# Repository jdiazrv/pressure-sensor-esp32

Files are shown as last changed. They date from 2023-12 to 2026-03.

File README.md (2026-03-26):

# ESP32 Pressure Sensor for MAB WaterMaker

ESP32-based dual pressure monitor for a MAB WaterMaker system.
It reads two 0.5-4.5 V pressure transducers through an ADS1115, shows the values on a local dashboard and OLED, and publishes the data to SignalK over UDP.

This project is the ESP32 evolution of the original `8266-pressure-sensor`, adapted for the same hardware concept and marine workflow with a more complete web UI, better diagnostics, demo modes, OTA updates, and more robust SignalK discovery.

## Release Notes

### v1.5

- LED state machine consolidated and aligned with connectivity/error priorities
- Fast dual-LED blink alarm when ADS1115 is missing in real mode
- ADS1115 startup detection across addresses `0x48-0x4B` with I2C diagnostics on failure
- Dashboard now includes sensor voltages on both pressure cards
- Manual SignalK target now accepts `ip:port` in UI
- Dashboard `Last reading` update made robust
- Min/max range markers consolidated into periodic one-minute updates
- Removed duplicated card status text while preserving color status chip (`Warning/Normal/Alarm`)

## Features

- Dual pressure acquisition with ADS1115
- OLED local display
- Responsive dashboard served from LittleFS
- SignalK UDP output with automatic discovery
- Manual SignalK IP override from the UI
- Configurable and persistent UDP port
- Real, Demo, and Demo + UDP modes
- Device diagnostics page
- SignalK monitor page with live scrolling log
- Firmware OTA update from the browser
- Filesystem OTA update from the browser
- AP mode or client mode with WiFiManager fallback
- Detection of:
  - ADS1115 missing
  - no signal from sensor
  - disconnected sensor
  - stale sensor data

## Hardware

- ESP32 dev board
- ADS1115 ADC
- 2 pressure sensors with 0.5-4.5 V output
- Small I2C OLED
- 5 V regulated supply

The original hardware concept and documentation come from the earlier 8266 project and are still relevant here.

## Pressure Channels

- Sensor 1: low pressure / inlet pressure
- Sensor 2: high pressure / main pressure

Default calibration:

- Sensor 1: `0.5-4.5 V` => `0-15 bar`
- Sensor 2: `0.5-4.5 V` => `0-80 bar`

Dashboard visual ranges:

- Low pressure gauge: `0-4 bar`
- High pressure gauge: `0-70 bar`

## WiFi Modes

`Client`

- Connects to an existing WiFi network
- Tries to discover a SignalK server with mDNS
- Publishes UDP to the configured or discovered target

`AP only`

- Creates a local access point for direct access
- Useful for standalone setup and service work

## Sensor Source Modes

`Real`

- Reads ADS1115 hardware
- Sends UDP only when ADS1115 is detected

`Demo`

- Generates realistic simulated pressures
- Does not send UDP

`Demo + UDP`

- Generates simulated pressures
- Sends them through the same UDP pipeline for testing

## Web Interface

Main dashboard:

- Large low and high pressure cards
- RSSI indicator
- SignalK status pill
- Clickable status details with firmware/UI version and current error

Settings:

- Calibration for both sensors
- WiFi mode
- sensor source mode
- AP password
- SignalK retry count
- SignalK IP
- UDP port

Maintenance:

- firmware update
- filesystem update
- tools
- factory reset

Tools:

- device diagnostics
- SignalK monitor

## OTA Updates

The device supports browser-based OTA:

- `/update` for firmware
- `/updatefs` for LittleFS filesystem image

It also exposes ArduinoOTA for LAN updates.

## SignalK Output

The device publishes:

- `environment.watermaker.pressure.low`
- `environment.watermaker.pressure.high`

Current mapping:

- low pressure comes from Sensor 1
- high pressure comes from Sensor 2

## Filesystem Content

The web UI is stored in `data/` and uploaded to LittleFS.

Important files:

- `data/index.html`
- `data/gauge.min.js`
- `data/manifest.webmanifest`
- `data/icon.svg`

## Build And Upload

This project uses PlatformIO.

### Build

```bash
platformio run -e esp32dev
```

### Upload Firmware

```bash
platformio run -e esp32dev -t upload
```

### Upload Filesystem

```bash
platformio run -e esp32dev -t uploadfs
```

### Serial Monitor

```bash
platformio device monitor -b 115200
```

## Project Structure

- [`src/main.cpp`](src/main.cpp): firmware logic
- [`src/config_html.h`](src/config_html.h): settings page HTML
- [`data/index.html`](data/index.html): dashboard UI
- [`platformio.ini`](platformio.ini): PlatformIO environment
- [`res/gauges.jpeg`](res/gauges.jpeg): legacy gauge reference
- [`res/Schematics.png`](res/Schematics.png): hardware reference
- [`res/pressure_pcb.png`](res/pressure_pcb.png): PCB reference
- [`res/pressure_bom.html`](res/pressure_bom.html): BOM reference

## Legacy Reference

This repository derives from the original 8266 project:

- https://github.com/jdiazrv/8266-pressure-sensor

Relevant hardware concepts, gauge ranges, PCB references, and documentation were carried forward and adapted for the ESP32 implementation.

## License

See [LICENSE.md](LICENSE.md).

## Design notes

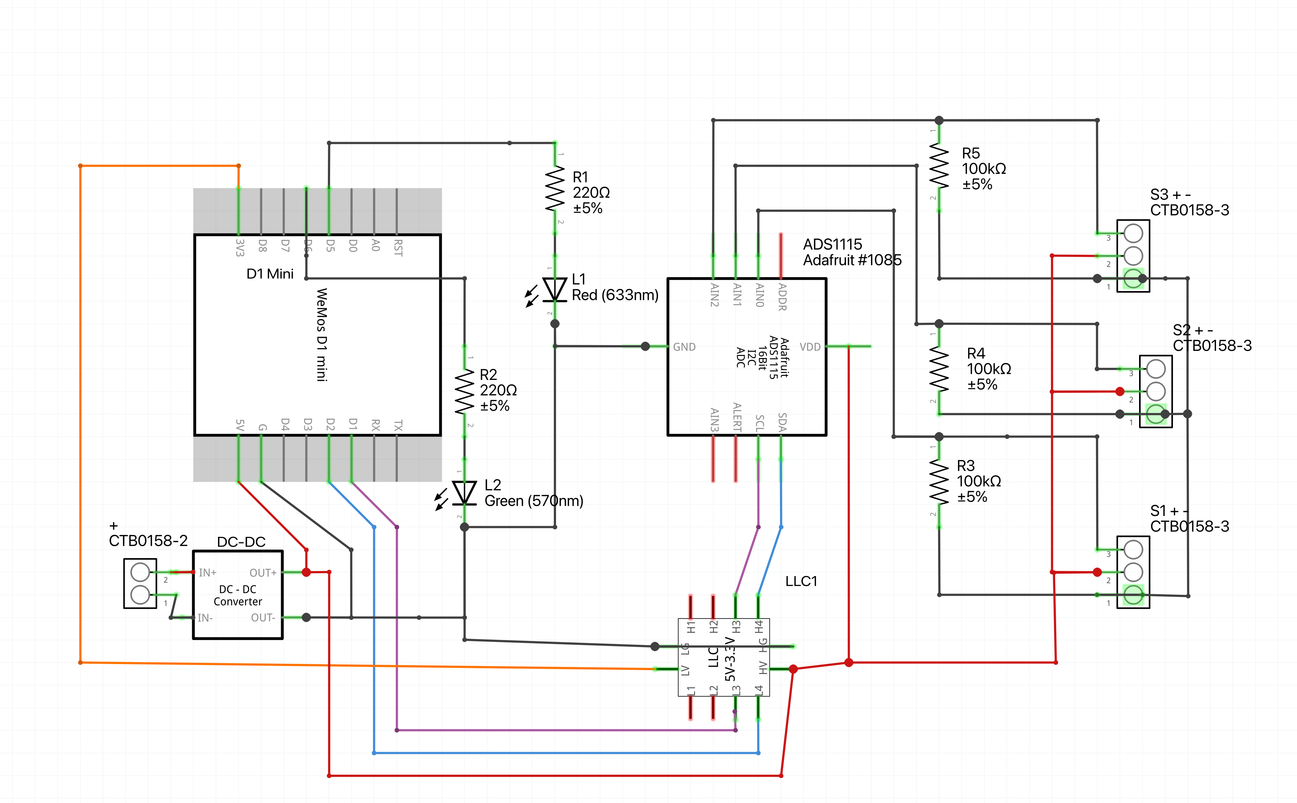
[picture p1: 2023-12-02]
res/Schematics.png

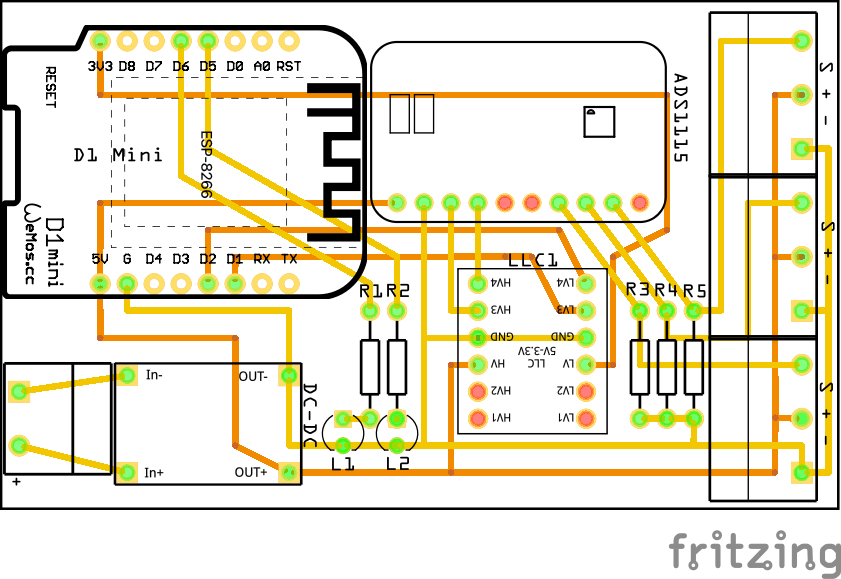
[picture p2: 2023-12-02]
res/pressure_pcb.png

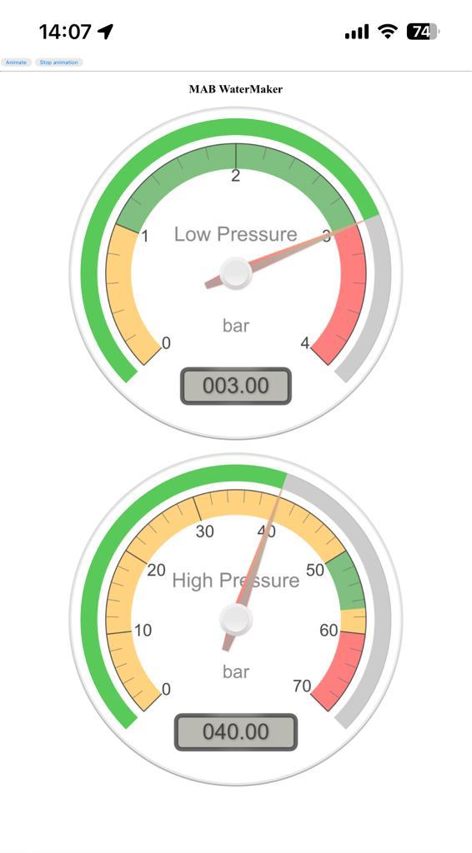
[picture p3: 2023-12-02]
res/gauges.jpeg

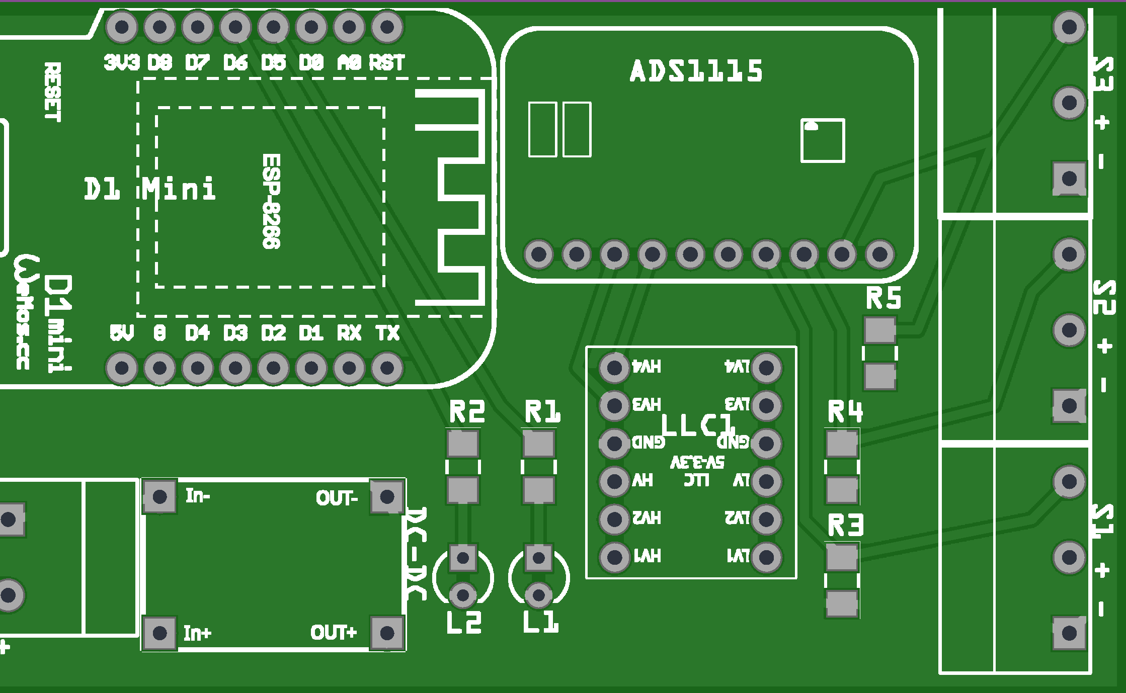
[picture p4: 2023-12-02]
res/PCB.png

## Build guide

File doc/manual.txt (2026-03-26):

MAB WaterMaker - Pressure Sensor ESP32
Manual operativo (v1.5)

1) Resumen
- El equipo mide dos presiones con ADS1115.
- Publica datos por web local y por UDP para SignalK.
- Permite modo real, demo y demo+UDP.

2) Entradas y canales
- Sensor 1: presion baja (feed/inlet).
- Sensor 2: presion alta (main).
- Rango por defecto de sensores: 0.5-4.5 V.

3) Red y acceso
- En modo cliente (STA), intenta conectarse al WiFi configurado.
- Si no hay credenciales, levanta portal de configuracion con WiFiManager.
- Dashboard principal: / (raiz del dispositivo).
- Ajustes: /config.

4) SignalK
- Descubrimiento automatico por mDNS.
- Configuracion manual de IP desde dashboard.
- Se acepta formato ip o ip:puerto (ejemplo: 192.168.1.10:3000).
- Puerto de servicio SignalK por defecto: 3000.
- Puerto UDP configurable (por defecto 4210).

5) Indicacion por LEDs (v1.5)
- Error ADS1115 en modo real: parpadeo rapido en los dos LEDs.
- AP only: LED1 doble pulso, LED2 apagado.
- WiFi desconectado/conectando: LED1 parpadeo medio (o triple pulso en ventana portal), LED2 apagado.
- WiFi conectado:
	- SignalK buscando: LED2 doble pulso.
	- SignalK OK: LED2 fijo (si no hay timeout de datos).
	- SignalK sin respuesta: LED2 parpadeo medio.

6) Dashboard (v1.5)
- Muestra presion baja/alta y voltaje de cada canal.
- Chip de estado por color: Warning / Normal / Alarm.
- "Last reading" actualizado de forma robusta.
- Marcadores min/max de barra actualizados periodicamente en bloques de 1 minuto.

7) Deteccion ADS1115
- Escaneo de direcciones validas: 0x48, 0x49, 0x4A, 0x4B.
- Si no lo detecta, registra diagnostico I2C por serie.

8) OTA
- Firmware: /update.
- Filesystem: /updatefs.

9) Build y carga (PlatformIO)
- Compilar firmware: platformio run -e esp32dev
- Subir firmware: platformio run -e esp32dev -t upload
- Subir filesystem: platformio run -e esp32dev -t uploadfs

10) Notas de diagnostico
- Si no hay lecturas en modo real: verificar alimentacion, GND comun, cableado ADS1115, y direccion ADDR.
- Si hay dashboard pero no SignalK: revisar IP/puerto, mDNS y firewall de la red.

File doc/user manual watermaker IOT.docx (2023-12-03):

# WaterMaker IoT Pressure Monitor: User Guide

## Welcome

Welcome to the WaterMaker IoT Pressure Monitor, an innovative device designed for the MAB WaterMaker system (http://watermaker.se). While the MAB WaterMaker system is fully functional with its incorporated analog devices, this device adds an extra layer of monitoring and convenience, allowing you to monitor and receive alerts even when away from the watermaker's control panel, like in the cockpit of the vessel. This user guide will provide you with detailed information about the setup, use, and how to integrate this device into your monitoring system.

## Device Functionality

The MAB WaterMaker is equipped with all indicators for its operation in a safe manner. However, it is convenient to regularly monitor the pressures while it works to ensure proper functioning. This can be done by looking at the watermaker control panel or remotely with this device.

The device is equipped with two high-precision pressure sensors. These sensors are responsible for measuring and recording the pressure in your water purification system. The sensors operate in different pressure ranges:

- The first sensor monitors low-pressure circuits and can measure values in the range of 0 to 4 bar.
- The second sensor takes care of high-pressure circuits and can record values in the range of 0 to 70 bar.

## Operating Modes

The device can operate in two main modes: Station and AP (Access Point).

1. Station Mode: In this mode, the device connects to an existing WiFi network. You can configure the device to connect to your home WiFi network or to a specific network on your vessel. If for some reason it cannot connect to the preconfigured network (for example, if the network is not available or incorrect credentials were entered), the device will initiate and temporarily create a WiFi network called 'watermaker_config'. This will allow you to select or reconfigure the WiFi network directly from the device. Also, in this mode, the software will automatically search for the SignalK server, simplifying integration with boat instrumentation systems.
2. AP (Access Point) Mode: In this mode, the WaterMaker IoT Pressure Monitor creates its own WiFi network called 'watermaker'. This mode is useful when you do not have access to an existing WiFi network. You can configure a password for this WiFi network to ensure secure access. You can access the device in this mode through the hostname 'watermaker.local' or via the default IP address '192.168.4.1'.

## Remote Monitoring

A standout feature of this device is its ability to allow remote monitoring of your WaterMaker system. This means you can check the status of your system in real time from any location. Whether you are inside your vessel or on land (if you have configured the router for remote access), you can access the pressure data and ensure that your system is functioning correctly.

## Web Interface for Pressure Monitoring


Once you access watermaker.local through your web browser, the interface will show two radial gauges, each displaying a different aspect of the watermaker's operation:

### Low Pressure Gauge

- Range: 0 to 4 bar
- Color-Coded Highlights:
  - Orange Zone (0-1 bar): Low-pressure warning.
  - Green Zone (1-3 bar): Normal operating pressure range.
  - Red Zone (3-4 bar): High-pressure warning.

### High Pressure Gauge

- Range: 0 to 70 bar
- Color-Coded Highlights:
  - Orange Zone (0-50 bar): Preparatory pressure range.
  - Green Zone (50-57 bar): Normal operating pressure range.
  - Orange Zone (57-60 bar): Transition or caution area.
  - Red Zone (60-70 bar): High-pressure warning.

These gauges are designed to provide clear and intuitive feedback on the system's status, with green zones specifically marking the ideal operating pressures. Users can conveniently monitor the watermaker's performance and ensure it operates within safe and efficient pressure ranges. Data is received in the SignalK Server, consequently it can be displayed with KIP or with third-party apps such as WillHelm SK.

## Sensor configuration

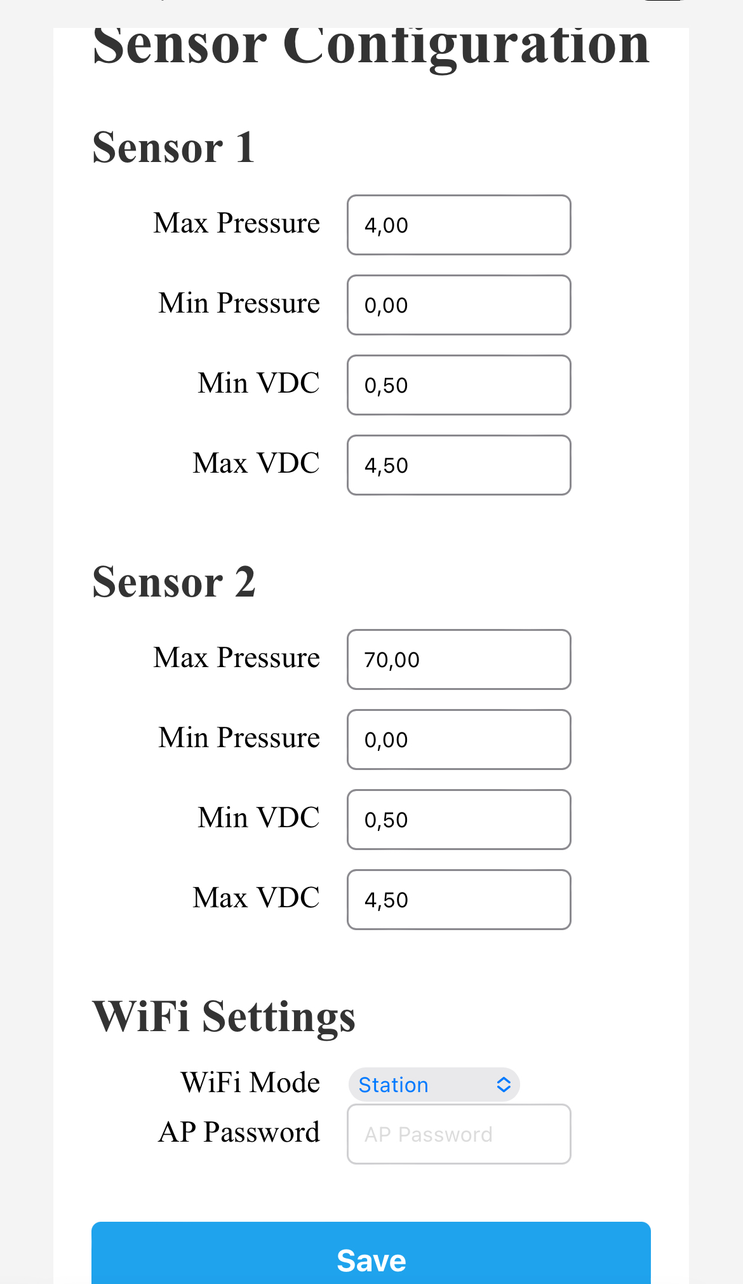
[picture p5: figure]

The sensors used in the WaterMaker IoT Pressure Monitor must meet certain specifications to function properly with the device. Here are the key specifications they should adhere to:

1. Power Supply: The sensors should be capable of operating with a 5VDC power source. This means they should be able to function with a voltage of 5 volts of direct current.
2. Maximum Signal Voltage: The sensor should be able to provide a voltage signal within the range of 0 to 4.5 volts, depending on the maximum pressure expected to be measured. This ensures that the sensor can effectively transmit pressure information to the WaterMaker IoT Pressure Monitor.
3. Threaded Connection: For sensor installation, a high-pressure "T" with a male G1/4 thread, a female G1/4 thread, and a female thread that matches the sensor's thread should be used. This ensures a proper and sealed connection for accurate pressure measurement.

As for sensor configuration, it is done on the configuration page, which can be accessed in two ways:

- From the wheel icon in the upper-right corner of the "gauges" screen in the web interface of the WaterMaker IoT Pressure Monitor.
- Directly by entering the web address "watermaker.local/config" in a web browser.

On this configuration page, users can adjust sensor parameters such as pressure ranges to match the specific characteristics of the sensor they are using. This ensures that the sensors are correctly configured to provide accurate measurements and adapt to the expected operating conditions.

## Indicator Lights

Red LED (Status Indicator)

- Solid On: The red LED remains solidly lit when the device is powered. This indicates that the device is receiving power and is operational.
- LED Off: The red LED turns off when the device successfully establishes a connection to the network. This signifies that the device is connected to a network, either through Station Mode (connecting to an existing WiFi network) or Access Point (AP) Mode (creating its own WiFi network).
- Blinking (Flashing): The red LED blinks or flashes each time data is transmitted to the SignalK server. This serves as a visual confirmation that the device is actively sending pressure data to the SignalK server, indicating its functionality and data communication activity.

## Integration with SignalK

The device is designed to automatically connect to the SignalK server when in Station mode. SignalK is an open-source standard for boat navigation that allows the integration of data from different systems and sensors. The WaterMaker IoT Pressure Monitor sends pressure data to the SignalK server via port 4210. This allows you to use SignalK-compatible monitoring applications to visualize and analyze the pressure data.

## SignalK Configuration

The WaterMaker IoT Pressure Monitor is designed to automatically connect to the SignalK server when in Station mode. The device will send data through port 4210 of the SignalK server. To configure the SignalK server and receive data from the device, follow these steps:

- Access the SignalK Web Interface: Open the SignalK web interface from your web browser and make sure you are logged into your SignalK account if necessary.
- Navigate to Connection Configuration: In the SignalK web interface, look for the connection configuration section or data sources. This is usually found in server settings or a similar configuration menu.
- Add a New UDP Connection: Within the connection configuration section, look for the option to add a new UDP connection. It may have a name like "Add Connection" or similar.
- Configure the UDP Connection:
  - Data Type: Specify "SignalK" as the expected data type.
  - UDP Port: Enter "4210" as the UDP port number to which the WaterMaker IoT Pressure Monitor will send data.
- Save the Configuration: Once you have specified the data type as "SignalK" and configured the UDP port as "4210", make sure to save the settings. You will usually find a button or an option to save changes.
- Verify the Configuration: After saving the settings, verify that the UDP connection is active and working correctly. You can check the SignalK web interface to confirm that the data is being received and processed according to the SignalK standard.

By following these steps, you will have correctly set up a UDP connection in SignalK to receive data from the WaterMaker IoT Pressure Monitor on port 4210. This will allow SignalK to interpret and process the pressure data according to the SignalK standard, facilitating its visualization and analysis in SignalK-compatible applications or on the SignalK web interface.

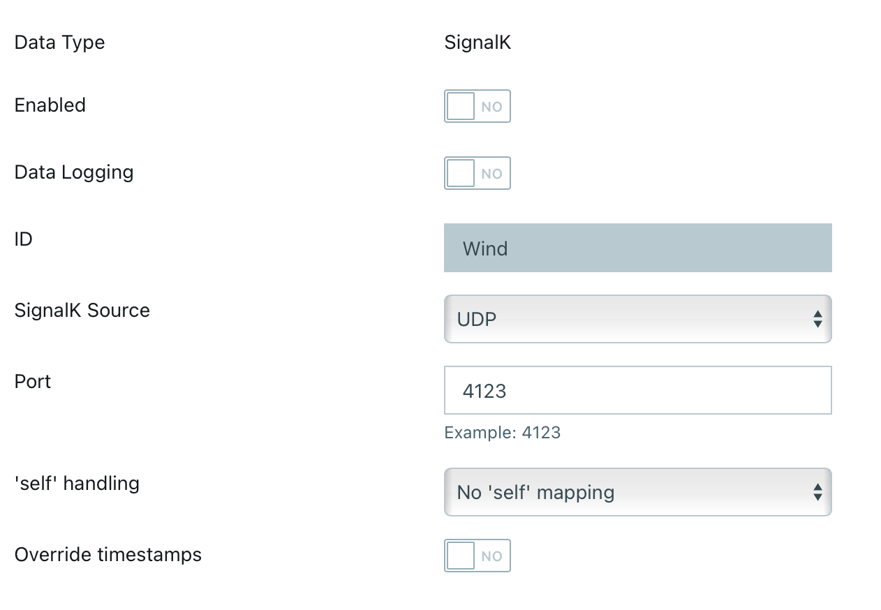
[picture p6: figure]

## Custom Alerts

In addition to real-time monitoring, the WaterMaker IoT Pressure Monitor allows you to set up custom alerts. You can set specific pressure thresholds and receive instant notifications in case abnormal pressure conditions are detected. These alerts provide an additional layer of safety and allow you to take immediate action in case of issues with your WaterMaker system. The configuration of the alerts is done on the SignalK server with the necessary plugins or for advanced users with Node-red.

## Access Point (AP) Password Reset

If you forget the configured password for the AP (Access Point) mode on the WaterMaker IoT Pressure Monitor, you can reset it to the default factory password, which is "12345678". Follow these steps to do so:

1. Locate the physical reset button on the WaterMaker IoT Pressure Monitor device.
2. Briefly press the reset button once. It is not necessary to hold it pressed for a long time.
3. After pressing the reset button, the AP password will automatically reset to the default password "12345678".
4. You can now connect to the AP mode using the default password "12345678".

Remember that, after resetting the AP password, it is advisable to set a new secure password to ensure the security of your network. You can do this through the device's web configuration interface.

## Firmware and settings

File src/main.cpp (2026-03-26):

// Pressure Sensor ESP32 - SignalK Watermaker
// Based on Chain Counter ESP32 mejorado v3.7
// Dual pressure sensor with SignalK integration
// Changelog:
//   v1.6
//     Change: UDP send interval reduced from 2s to 1s for faster APK updates
//     Add: voltage1 and voltage2 included in UDP payload for APK display
//   v1.5
//     Add: LED state-machine patterns aligned with project status priorities
//     Add: both LEDs blink fast when ADS1115 is missing in real mode
//     Fix: ADS1115 detection scans all valid addresses (0x48-0x4B) with I2C diagnostics
//     Fix: dashboard renders live bars when readings are available even with device warnings
//     Add: voltage values in /pressure JSON and on both dashboard cards
//     Fix: SignalK manual target accepts ip:port format from UI
//     Fix: Last reading timestamp updates reliably in dashboard polling loop
//     Change: min/max range markers now update with periodic one-minute buckets
//     Change: removed duplicated card status text while keeping color label chip
//   v1.4
//     Add: I2C mutex for bus serialization (ADS1115 + OLED)
//     Add: OtaState struct for coherent OTA state management
//     Add: RuntimeState struct for sensor/runtime data encapsulation
//     Add: UDP resync helpers (invalidateUdpLastSent, resetUdpPressureHistory)
//     Add: Display refresh separated from page switching (1s vs 5s)
//     Add: Sensor reading refactored into cohesive helpers
//     Fix: OLED access removed from taskNetwork (no cross-core I2C race)
//     Fix: All I2C operations protected with lockI2C()
//     Fix: OTA handlers use otaState.error as single source of truth
//     Fix: WiFi reconnection uses WiFi.begin() without cached credentials
//     Fix: Event_Submit preserves existing values when fields missing
//     Fix: Event_MonitorData minimizes lock time (snapshot pattern)
//     Fix: SignalK IP handler reads servicePort under lock
//     Fix: OLED startup screen wrapped with i2cMutex
//     Fix: showNetworkPage passed as parameter (no global state)
//     Fix: signalkCtx initialization under lockState in readPreferences()
//     Fix: ConfigSnapshot separated from runtime state
//     Change: updatePressureReadings split into focused helpers
//     Change: writePreferences split into config/signalK/runtime domains
//     Change: applySettingsPayload uses unified SignalK source-of-truth
//     Remove: dead globals (pressure1/2, voltage1/2, previousMillis, intervalForAP, isFirstBoot)
//   v1.3
//     Add: dedicated mutex for monitor ring buffer reads/writes
//     Fix: preserve discovered SignalK service port when saving settings
//     Fix: monitor API now reads buffered lines under monitor lock
//     Fix: sensor/error debug logging now snapshots shared values before logging
//     Fix: pressure/meta/state JSON now use consistent escaping for error text
//     Change: settings JSON parsing now applies overrides on top of the current payload state
//     Change: submit/settings handlers now use runtime snapshots instead of raw shared reads
//   v1.2
//     Add: password-only auth on config, OTA and factory reset routes
//     Add: dedicated admin credentials separated from AP password
//     Add: lightweight admin session cookie for protected routes
//     Add: shared-state mutex for sensor/network/runtime snapshots
//     Add: I2C bus hardening with 100 kHz clock and timeout
//     Add: password confirmation and reveal toggles on device settings
//     Change: /config now opens a public settings menu and /device-settings stays protected
//     Change: device settings page focuses on settings only, without maintenance shortcuts
//     Change: dashboard and admin UI text unified in English
//     Change: runtime NVS checkpoint relaxed to 15 min to reduce flash wear
//   v1.1
//     Fix: Sensor 2 factory max pressure corrected to 80 bar
//     Fix: SignalK UDP mapping corrected to low/high semantic paths
//     Add: SignalK HTTP health probe via /signalk every 15 s
//     Add: automatic rediscovery when a previously reachable SignalK server disappears
//     Fix: dashboard SignalK pill now reflects real server availability
//     Fix: dashboard uses backend data validity instead of guessing from pressure values
//     Fix: UDP monitor distinguishes local send success from local send failure
//   v1.0
//     Add: SignalK discovery with robust .local hostname resolution
//     Fix: do not overwrite configured UDP port with SignalK websocket service port
//     Add: persistent SignalK IP and UDP port configuration in NVS
//     Add: sensor source modes Real / Demo / Demo + UDP
//     Add: HTTP OTA for firmware and filesystem update
//     Add: UI status details with FW/UI version and device error reporting
//     Add: ADS1115 missing, no-signal, and disconnected sensor detection
//     Add: SignalK IP edit from UI and LittleFS-served dashboard updates

#include <Arduino.h>
#include <WiFi.h>
#include <WebServer.h>
#include <Preferences.h>
#include <WiFiUdp.h>
#include <ESPmDNS.h>
#include <WiFiManager.h>
#include <Update.h>
#include <Wire.h>
#include <Adafruit_ADS1X15.h>
#include <Adafruit_GFX.h>
#include <Adafruit_SSD1306.h>
#include <ArduinoJson.h>
#include <LittleFS.h>
#include "config_html.h"

// ── Versión del software ───────────────────────────────────────────────────────
#define SW_VERSION "v1.6"

// ── Nivel de debug ──────────────────────────────────────────────────────────────
// 0 = sin logs
// 1 = errores
// 2 = info
// 3 = verbose
#define DEBUG_LEVEL_ERROR 1
#define DEBUG_LEVEL_INFO 2
#define DEBUG_LEVEL_VERBOSE 3
#define DEBUG 0

// Macros de logging
#define LOG_ERR(msg)                      \
    do                                    \
    {                                     \
        if (DEBUG >= DEBUG_LEVEL_ERROR)   \
            Serial.println("[ERR] " msg); \
    } while (0)
#define LOG_ERRF(fmt, ...)                                   \
    do                                                       \
    {                                                        \
        if (DEBUG >= DEBUG_LEVEL_ERROR)                      \
            Serial.printf("[ERR] " fmt "\n", ##__VA_ARGS__); \
    } while (0)
#define LOG_INF(msg)                      \
    do                                    \
    {                                     \
        if (DEBUG >= DEBUG_LEVEL_INFO)    \
            Serial.println("[INF] " msg); \
    } while (0)
#define LOG_INFF(fmt, ...)                                   \
    do                                                       \
    {                                                        \
        if (DEBUG >= DEBUG_LEVEL_INFO)                       \
            Serial.printf("[INF] " fmt "\n", ##__VA_ARGS__); \
    } while (0)
#define LOG_VRB(msg)                      \
    do                                    \
    {                                     \
        if (DEBUG >= DEBUG_LEVEL_VERBOSE) \
            Serial.println("[VRB] " msg); \
    } while (0)
#define LOG_VRBF(fmt, ...)                                   \
    do                                                       \
    {                                                        \
        if (DEBUG >= DEBUG_LEVEL_VERBOSE)                    \
            Serial.printf("[VRB] " fmt "\n", ##__VA_ARGS__); \
    } while (0)

// ── Valores por defecto / fábrica ───────────────────────────────────────────────
#define MIN_VOLTAGE1 0.5
#define MAX_VOLTAGE1 4.5
#define MIN_PRESSURE1 0
#define MAX_PRESSURE1 15
#define MIN_VOLTAGE2 0.5
#define MAX_VOLTAGE2 4.5
#define MIN_PRESSURE2 0
#define MAX_PRESSURE2 80
#define MAX_AP_PASSWORD_LENGTH 20
#define AP_PASSWORD "12345678"
#define ADMIN_USERNAME "admin"
#define ADMIN_PASSWORD "12345678"
#define WIFI_MODE 1
#define SENSOR_MODE_REAL 0
#define SENSOR_MODE_DEMO 1
#define SENSOR_MODE_DEMO_UDP 2
#define DEFAULT_SIGNALK_MAX_ATTEMPTS 12
#define DEFAULT_UDP_PORT 4210

// SignalK timing - FAST right after events, SLOW in steady state
#define SIGNALK_PROBE_FAST_MS 5000UL
#define SIGNALK_PROBE_SLOW_MS 60000UL
#define SIGNALK_DISCOVERY_FAST_MS 5000UL
#define SIGNALK_DISCOVERY_SLOW_MS 60000UL
#define SIGNALK_RETRY_MS 60000UL  // Legacy, kept for compatibility

#define SIGNALK_TCP_PROBE_TIMEOUT_MS 500
#define RUNTIME_START_LOW_PRESSURE_BAR 1.0f
#define RUNTIME_STOP_HIGH_PRESSURE_BAR 10.0f
#define UDP_SEND_INTERVAL_MS 1000UL
#define UDP_AVERAGE_WINDOW 5
#define RUNTIME_CHECKPOINT_MS 900000UL
#define SENSOR_DISCONNECT_TOLERANCE_V 0.2f
#define SENSOR_NO_SIGNAL_V 0.05f
#define MONITOR_BUFFER_SIZE 160
#define MONITOR_LINE_MAX_LEN 80
#define SENSOR_REFRESH_MS 250
#define DISPLAY_REFRESH_MS 1000
#define DISPLAY_PAGE_MS 5000
#define NETWORK_TASK_DELAY_MS 50
#define I2C_CLOCK_HZ 100000UL
#define I2C_TIMEOUT_MS 50
#define AUTH_SESSION_TTL_MS 1800000UL

// ── OLED ────────────────────────────────────────────────────────────────────────
#define SCREEN_WIDTH 64
#define SCREEN_HEIGHT 48
#define OLED_ADDR 0x3C
#define OLED_SDA 21
#define OLED_SCL 22

Adafruit_SSD1306 display(-1);  // RST = -1 (no reset pin)
bool displayAvailable = false;

// ── Variables globales ──────────────────────────────────────────────────────────
Preferences prefs;
SemaphoreHandle_t stateMutex = nullptr;
SemaphoreHandle_t prefsMutex = nullptr;  // Mutex for NVS/Preferences operations
SemaphoreHandle_t monitorMutex = nullptr;
SemaphoreHandle_t i2cMutex = nullptr;    // Mutex for I2C bus (ADS1115, OLED)

// ── SignalK State Machine ────────────────────────────────────────────────────────
enum SignalKState : uint8_t
{
    SK_OFF = 0,
    SK_SEARCHING = 1,
    SK_READY = 2
};

struct SignalKContext
{
    SignalKState state = SK_OFF;
    IPAddress targetIp = IPAddress(0,0,0,0);
    uint16_t servicePort = 3000;
    uint16_t udpPort = DEFAULT_UDP_PORT;

    bool manualTarget = false;
    bool targetHealthy = false;
    bool hadSuccessfulProbe = false;

    uint8_t discoveryAttempts = 0;
    unsigned long lastDiscoveryAttemptMs = 0;
    unsigned long lastProbeMs = 0;
};

SignalKContext signalkCtx;

// Sensor configuration
float minVoltage1 = MIN_VOLTAGE1;
float maxVoltage1 = MAX_VOLTAGE1;
float minPressure1 = MIN_PRESSURE1;
float maxPressure1 = MAX_PRESSURE1;

float minVoltage2 = MIN_VOLTAGE2;
float maxVoltage2 = MAX_VOLTAGE2;
float minPressure2 = MIN_PRESSURE2;
float maxPressure2 = MAX_PRESSURE2;

// Network configuration
int wifiModeApSta = WIFI_MODE;
char APpassword[MAX_AP_PASSWORD_LENGTH + 1] = AP_PASSWORD;
char ssid_sta[33] = "";  // Max SSID length is 32
char password_sta[65] = "";  // Max WiFi password length is 64
int signalkMaxAttempts = DEFAULT_SIGNALK_MAX_ATTEMPTS;

int sensorMode = SENSOR_MODE_REAL;

// Device configuration
const char *hostName = "watermaker";
unsigned long startTime = 0;

// Monitor buffer (fixed-size circular buffer to avoid heap fragmentation)
char monitorLines[MONITOR_BUFFER_SIZE][MONITOR_LINE_MAX_LEN];
unsigned long monitorSeqStart = 0;
unsigned long monitorSeqNext = 0;

// OTA State
struct OtaState
{
    bool inProgress = false;
    bool wasRunning = false;
    unsigned long startMs = 0;
    size_t progressLogBytes = 0;
    char error[128] = "";  // Max error message length
    int command = U_FLASH;
    char label[16] = "firmware";  // "firmware" or "filesystem"
};

OtaState otaState;

// Runtime State
struct RuntimeState
{
    float pressure1 = 0.0f;
    float pressure2 = 0.0f;
    float voltage1 = 0.0f;
    float voltage2 = 0.0f;

    bool ads1115Found = false;
    bool tryingToConnect = false;
    unsigned long lastSensorUpdateMs = 0;

    char lastDeviceError[64] = "";  // Max error message length
    char lastLoggedDeviceError[64] = "";

    uint64_t totalRuntimeMs = 0;
    uint64_t runtimePersistedMs = 0;
    unsigned long runtimeStartMs = 0;
    bool runtimeRunning = false;
    bool runtimeActivePersisted = false;

    float udpPressure1History[UDP_AVERAGE_WINDOW] = {0};
    float udpPressure2History[UDP_AVERAGE_WINDOW] = {0};
    uint8_t udpPressureHistoryCount = 0;
    uint8_t udpPressureHistoryIndex = 0;
    float lastSentUdpPressure1 = NAN;
    float lastSentUdpPressure2 = NAN;
};

RuntimeState runtimeState;

// LED pins
#define LED_PIN 18
#define LED_PIN2 19

enum LedCode : uint8_t
{
    LED_CODE_OFF = 0,
    LED_CODE_ON,
    LED_CODE_BLINK_SLOW,
    LED_CODE_BLINK_MEDIUM,
    LED_CODE_BLINK_FAST,
    LED_CODE_DOUBLE_PULSE,
    LED_CODE_TRIPLE_PULSE,
};

LedCode led1Code = LED_CODE_OFF;
LedCode led2Code = LED_CODE_OFF;
unsigned long led1PatternStartMs = 0;
unsigned long led2PatternStartMs = 0;
unsigned long wifiPortalNoticeUntilMs = 0;

char adminPassword[65] = ADMIN_PASSWORD;  // Max 64 chars + null
char adminSessionToken[33] = "";  // 32 hex chars + null
unsigned long adminSessionExpiresMs = 0;

// ADS1115
Adafruit_ADS1115 ads;

// Web server and network utilities
WebServer server(80);
WiFiManager wifiManager;
WiFiUDP Udp;
TaskHandle_t networkTaskHandle = nullptr;

// ── Utilities ───────────────────────────────────────────────────────────────────

float adcToVoltage(int16_t adcValue);
float mapToPressure(float voltage, float minVoltage, float maxVoltage, float minPressure, float maxPressure);
void addMonitorEvent(const char *tag, const char *message);

// Inline wrapper for String compatibility (use sparingly to avoid heap fragmentation)
inline void addMonitorEvent(const char *tag, const String &message)
{
    addMonitorEvent(tag, message.c_str());
}

String jsonEscape(const String &input);
String formatMillisBrief(unsigned long ms);
void taskNetwork(void *parameter);
void handleConnected();

// Sensor reading helpers
void readAdcSensors(float &outVoltage1, float &outVoltage2, float &outPressure1, float &outPressure2);
void calculateDemoReadings(float &outVoltage1, float &outVoltage2, float &outPressure1, float &outPressure2);
void publishSensorReadings(float voltage1, float voltage2, float pressure1, float pressure2);
void logSensorData();

struct DeviceSettingsPayload
{
    float maxPressure1;
    float minPressure1;
    float minVoltage1;
    float maxVoltage1;
    float maxPressure2;
    float minPressure2;
    float minVoltage2;
    float maxVoltage2;
    int wifiModeApSta;
    int sensorMode;
    int signalkMaxAttempts;
    unsigned int outPort;
    String signalkIp;
    String apPassword;
    String adminPassword;
    uint64_t totalRuntimeMs;
};

struct ConfigSnapshot
{
    float maxPressure1;
    float minPressure1;
    float minVoltage1;
    float maxVoltage1;
    float maxPressure2;
    float minPressure2;
    float minVoltage2;
    float maxVoltage2;
    int wifiModeApSta;
    int sensorMode;
    int signalkMaxAttempts;
    char apPassword[MAX_AP_PASSWORD_LENGTH + 1];
    char adminPassword[65];
    char ssidSta[33];
    char passwordSta[65];
};

void appendSettingsJson(String &json);
void sendSettingsJson();
bool validateSettingsPayload(const DeviceSettingsPayload &payload, String &errorMessage, IPAddress &parsedIp);
bool applySettingsPayload(const DeviceSettingsPayload &payload, bool jsonResponse);
bool readSettingsFromJson(DeviceSettingsPayload &payload, String &errorMessage);
void Event_ApiSettingsGet();
void Event_ApiSettingsPost();
void writePreferences();
void writeRuntimePreferences();
uint64_t currentPartialRuntimeMs();
uint64_t currentTotalRuntimeMs();
void updateRuntimeTracking();
bool ensureAuthenticated();
void handleAuthLogin();
bool hasAdminSession();
String makeSessionToken();
void sendPasswordPrompt();
void lockState();
void unlockState();
void lockMonitor();
void unlockMonitor();
void captureConfigSnapshot(ConfigSnapshot &snapshot);

struct SharedStateSnapshot
{
    float pressure1;
    float pressure2;
    float voltage1;
    float voltage2;
    IPAddress signalkIp;
    unsigned int udpPort;
    unsigned int signalkServicePort;
    bool adsFound;
    bool signalkAlive;
    bool runtimeRunning;
    bool runtimeActivePersisted;
    bool tryingToConnect;
    int wifiModeApSta;
    int sensorMode;
    int signalkMaxAttempts;
    char lastDeviceError[64];
    float udpAvgPressure1;
    float udpAvgPressure2;
    bool udpAverageReady;
};

void captureSharedState(SharedStateSnapshot &snapshot);
void recordUdpPressureSample(float lowPressure, float highPressure);
void resetUdpPressureHistory();
bool shouldSendUdpUpdate(SharedStateSnapshot &snapshot, float &outLow, float &outHigh);
void commitUdpSentValues(float low, float high);
bool sendUDP(const SharedStateSnapshot &snapshot);

// SignalK state management helpers
void tickSignalK();
void setSignalKManualTarget(IPAddress newIp, uint16_t newServicePort, bool persist);
void clearSignalKTarget(bool persist);
void handleLEDControl(unsigned long now);

static inline void setStatusLed(uint8_t pin, bool on)
{
    // Status LEDs are wired active-low on this board.
    digitalWrite(pin, on ? LOW : HIGH);
}

static bool evalLedPattern(unsigned long now, unsigned long startMs,
                           unsigned long onMs, unsigned long offMs,
                           uint8_t pulses, unsigned long gapMs)
{
    if (pulses == 0)
        return false;

    const unsigned long pulseSlot = onMs + offMs;
    const unsigned long activeWindow = pulseSlot * pulses;
    const unsigned long cycle = activeWindow + gapMs;
    if (cycle == 0)
        return false;

    const unsigned long t = (now - startMs) % cycle;
    if (t >= activeWindow)
        return false;

    const unsigned long inSlot = t % pulseSlot;
    return inSlot < onMs;
}

static bool ledCodeToOn(LedCode code, unsigned long now, unsigned long startMs)
{
    switch (code)
    {
        case LED_CODE_ON:
            return true;
        case LED_CODE_BLINK_SLOW:
            return evalLedPattern(now, startMs, 80, 2920, 1, 0);
        case LED_CODE_BLINK_MEDIUM:
            return evalLedPattern(now, startMs, 300, 300, 1, 0);
        case LED_CODE_BLINK_FAST:
            return evalLedPattern(now, startMs, 120, 120, 1, 0);
        case LED_CODE_DOUBLE_PULSE:
            return evalLedPattern(now, startMs, 140, 160, 2, 1100);
        case LED_CODE_TRIPLE_PULSE:
            return evalLedPattern(now, startMs, 120, 120, 3, 1100);
        case LED_CODE_OFF:
        default:
            return false;
    }
}

static void updateLedCode(LedCode newCode, LedCode &currentCode, unsigned long &patternStartMs, unsigned long now)
{
    if (newCode != currentCode)
    {
        currentCode = newCode;
        patternStartMs = now;
    }
}

bool isValidIP(const IPAddress &ip)
{
    return ip != IPAddress((uint32_t)0);
}

void lockState()
{
    if (stateMutex)
        xSemaphoreTake(stateMutex, portMAX_DELAY);
}

void unlockState()
{
    if (stateMutex)
        xSemaphoreGive(stateMutex);
}

void lockMonitor()
{
    if (monitorMutex)
        xSemaphoreTake(monitorMutex, portMAX_DELAY);
}

void unlockMonitor()
{
    if (monitorMutex)
        xSemaphoreGive(monitorMutex);
}

void lockI2C()
{
    if (i2cMutex)
        xSemaphoreTake(i2cMutex, portMAX_DELAY);
}

void unlockI2C()
{
    if (i2cMutex)
        xSemaphoreGive(i2cMutex);
}

struct SignalKPrefsSnapshot
{
    IPAddress targetIp;
    uint16_t servicePort;
    uint16_t udpPort;
    bool manualTarget;
};
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
void loop()
{
    static unsigned long lastSensorRefreshMs = 0;
    static unsigned long lastDisplayRefreshMs = 0;
    static unsigned long lastPageChangeMs = 0;
    static bool showNetworkPage = false;

    bool otaNow = Update.isRunning();
    bool otaWasRunningLocal = false;

    lockState();
    otaWasRunningLocal = otaState.wasRunning;
    unlockState();

    if (otaNow && !otaWasRunningLocal)
    {
        lockState();
        otaState.startMs = millis();
        otaState.wasRunning = true;
        unlockState();

        Serial.printf("[INF] HTTP OTA started - size: %u bytes, stack free: %u\n",
                      Update.size(), uxTaskGetStackHighWaterMark(NULL));
    }
    else if (!otaNow && otaWasRunningLocal)
    {
        unsigned long elapsed = 0;
        String otaError;
        lockState();
        elapsed = millis() - otaState.startMs;
        otaError = otaState.error;
        otaState.wasRunning = false;
        unlockState();

        if (otaError.length() > 0)
            Serial.printf("[ERR] HTTP OTA FAILED after %lums: %s\n", elapsed, otaError.c_str());
        else
            Serial.printf("[INF] HTTP OTA finished OK in %lums\n", elapsed);
    }

    unsigned long now = millis();
    handleLEDControl(now);

    bool otaBlocked = false;
    lockState();
    otaBlocked = otaState.inProgress;
    unlockState();

    if (otaBlocked || Update.isRunning())
    {
        server.handleClient();
        delay(1);
        return;
    }

    // Read sensors at 4 Hz. Pressure changes slowly enough that this keeps
    // the UI responsive while reducing unnecessary ADC/I2C work in the loop.
    if (millis() - lastSensorRefreshMs >= SENSOR_REFRESH_MS)
    {
        lastSensorRefreshMs = millis();
        updatePressureReadings();
    }

    updateRuntimeTracking();

    // Page switching: alternate between pressure and network pages every 5 seconds
    if (millis() - lastPageChangeMs >= DISPLAY_PAGE_MS)
    {
        lastPageChangeMs = millis();
        showNetworkPage = !showNetworkPage;
    }

    // Display refresh at DISPLAY_REFRESH_MS rate
    if (millis() - lastDisplayRefreshMs >= DISPLAY_REFRESH_MS)
    {
        lastDisplayRefreshMs = millis();
        if (canProduceReadings())
        {
            drawScreen(showNetworkPage);
        }
        else
        {
            drawErrorScreen("ADS1115 NOT FOUND", showNetworkPage);
        }
    }

    // HTTP server
    server.handleClient();
    delay(1);
}

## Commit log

2023-12-03 reubicacion de archivos
2023-12-18 delte fan-control
2024-02-21 changed led behaviour
    [pressure.fzz]
2026-03-22 Release initial ESP32 pressure sensor version
2026-03-23 Refine settings flow and unify UI language
2026-03-23 refactor: concurrent access fixes for production reliability
    Major concurrency improvements based on code analysis:
    1. 64-bit variable protection (HIGH priority)
    - All accesses to totalRuntimeMs, runtimePersistedMs, runtimeStartMs
    now protected under stateMutex
    - currentTotalRuntimeMs() and currentPartialRuntimeMs() take snapshots
    - Prevents corrupted runtime values on 32-bit ESP32
    2. Atomic sensor state publication (HIGH priority)
    - updatePressureReadings() calculates locally, publishes under lock
    - voltage1/2 and pressure1/2 updated atomically together
    - updateDeviceError() reads sensor state under lock
    3. UDP send confirmation fix (HIGH priority)
    - lastSentUdp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
    [main.cpp]
2026-03-23 refactor: SignalK state machine foundation (low risk)
    Add SignalKState enum and SignalKContext struct:
    - SK_DISABLED, SK_NO_TARGET, SK_DISCOVERING, SK_TARGET_KNOWN, SK_REACHABLE, SK_UNREACHABLE
    - Centralized context: targetIp, servicePort, discoveryAttempts, timing
    Add helper functions (not yet used by main logic):
    - setSignalKState() - state transitions with logging
    - setSignalKTarget() - atomic target update with optional persist
    - shouldAttemptSignalKDiscovery() - rate-limited discovery check
    - shouldAttemptSignalKProbe() - rate-limited probe check
    - updateSignalKStateOnWifiChange() - WiFi event handler
    Add FAST/SLOW timing:
    - SIGNALK_PROBE_FAST_MS (5s) for recent failures
    - SIGNALK_PRO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
    [main.cpp]
2026-03-23 refactor: SignalK probeSignalKServer usa state machine
    Update probeSignalKServer() to use new state-based logic:
    - shouldAttemptSignalKProbe() for rate limiting
    - setSignalKState(SK_REACHABLE/UNREACHABLE) for transitions
    - FAST retry (5s) when UNREACHABLE, SLOW (60s) otherwise
    - Automatic rediscovery trigger on probe failure
    Legacy compatibility maintained:
    - signalkServerReachable still updated
    - ip1, signalkServicePort still used as fallback
    - Existing behavior preserved
    Build verified: SUCCESS
    Flash: +524 bytes (within margin)
    [main.cpp]
2026-03-23 v1.4: Memory & concurrency hardening
    Major refactoring for production stability:
    Concurrency fixes:
    - Add I2C mutex for ADS1115 + OLED bus serialization
    - Remove OLED access from taskNetwork (no cross-core race)
    - Protect all I2C operations with lockI2C()
    - Move taskNetwork to Core 1 (avoid WDT on Core 0)
    - Add yield() after blocking MDNS/TCP operations
    - Increase NETWORK_TASK_DELAY_MS to 50ms
    Memory anti-fragmentation:
    - OtaState struct for coherent OTA state management
    - RuntimeState struct for sensor/runtime data encapsulation
    - Convert String globals to fixed char arrays (passwords, errors, SSIDs)
    - Monitor buffer: String[160] → char[160][80]
    - SharedStateSnapshot & ConfigSnapshot us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
    [main.cpp]
2026-03-23 Update: concurrent fixes and improvements
    [main.cpp]
2026-03-26 release: v1.5 dashboard, LED and ADS/SignalK updates
2026-03-26 v1.6: Faster UDP updates (1s) with voltage values for APK, disable debug logs
